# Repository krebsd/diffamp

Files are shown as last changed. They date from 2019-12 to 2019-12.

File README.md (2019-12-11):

# Differential Amplifier - diffamp

Differential Amplifier circuit for use for example in current sensing applications. The circuit is designed to be used in conjunction with an oscilloscope.

## PREFACE
This project and especially its documentation including this README is still in a very early state of development. This document will be updated with further information in the future.

## EDA

* [KiCad](http://kicad-pcb.org) - KiCad EDA is used for the PCB design

## Authors

* **David Krebs** - *Initial work* - [krebsd](https://github.com/krebsd)

## License

<br />This work is licensed under a <a rel="license" href="http://creativecommons.org/licenses/by-sa/4.0/">Creative Commons Attribution-ShareAlike 4.0 International License</a>

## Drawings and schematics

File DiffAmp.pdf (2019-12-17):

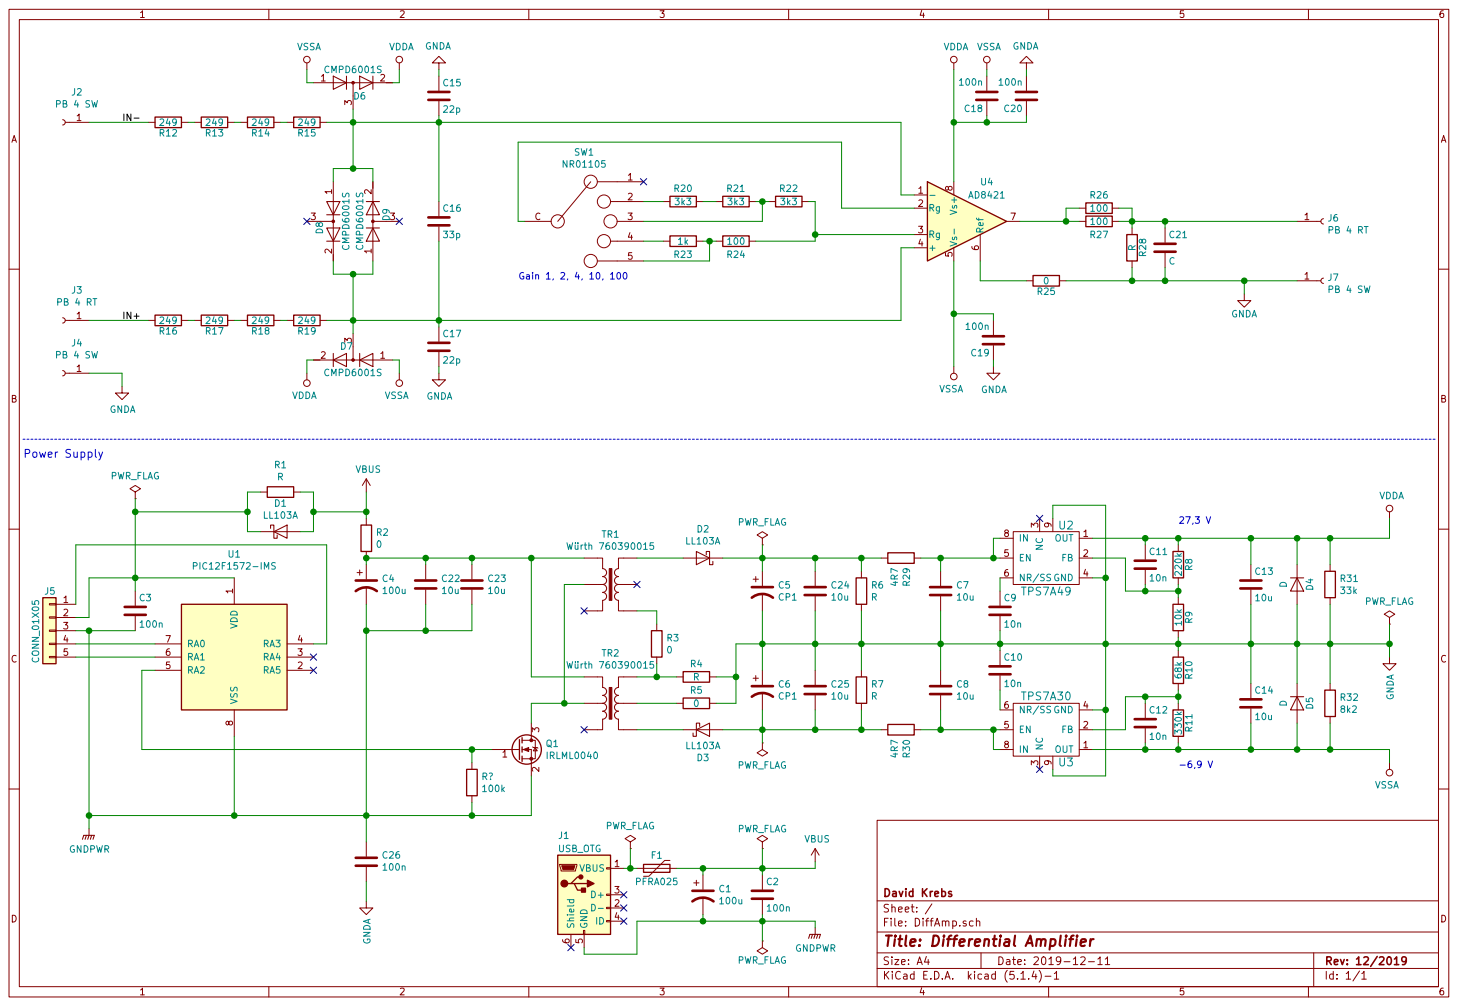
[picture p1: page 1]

File: DiffAmp.sch Sheet: / David Krebs D1

3 GND 4 EN 5 NR/SS 6

Id: 1/1 Title: Differential Amplifier

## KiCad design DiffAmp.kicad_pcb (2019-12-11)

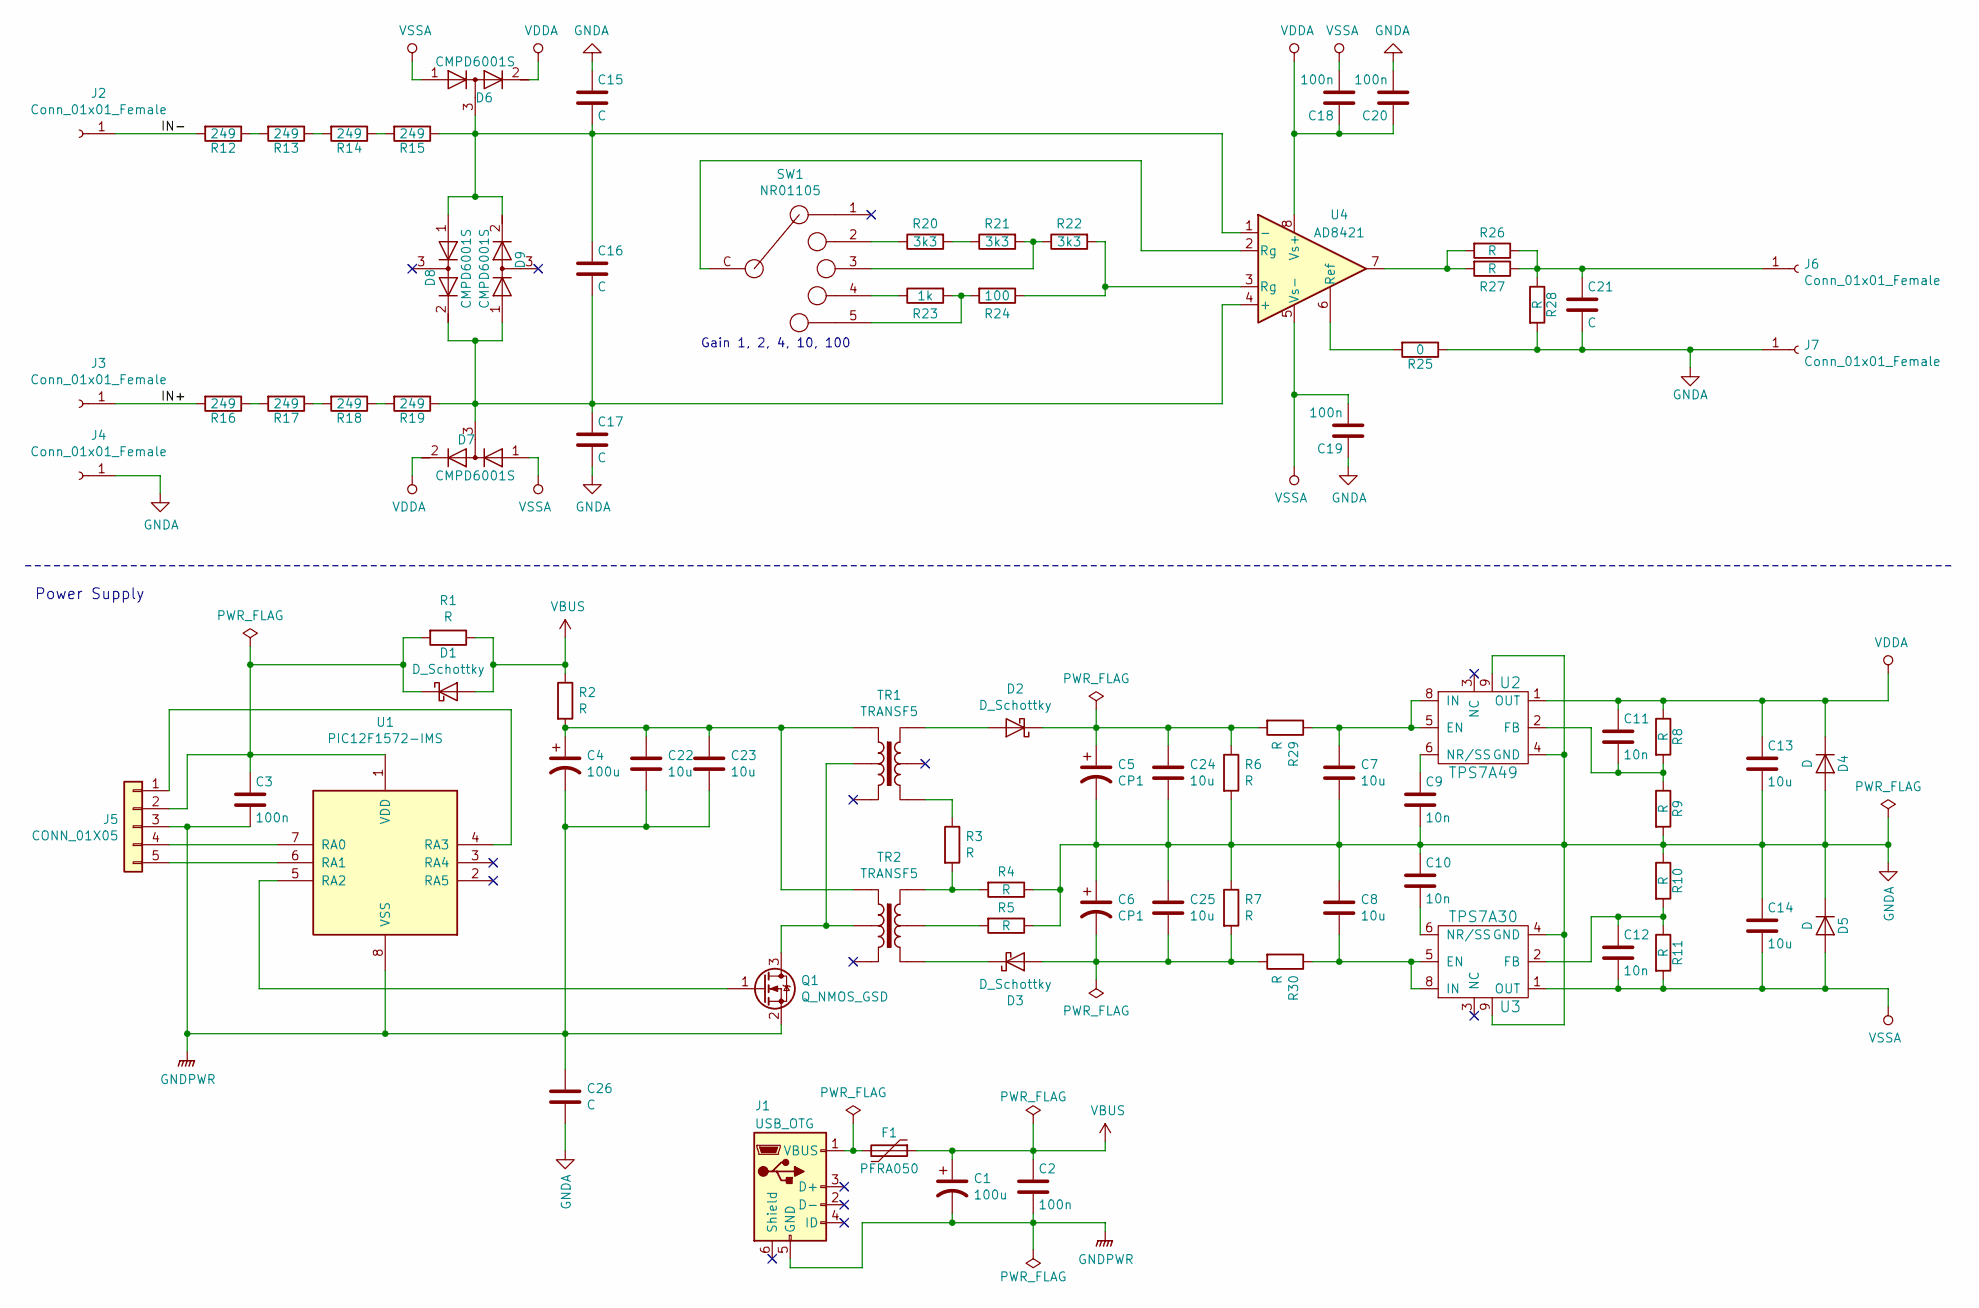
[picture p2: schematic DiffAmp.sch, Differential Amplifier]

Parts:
C1, C4: 100u; CP_Radial_D8.0mm_P3.50mm
C2, C3, C18, C19, C20: 100n; C_0805
C5, C6: CP1; CP_Radial_D8.0mm_P3.50mm
C7, C8, C22, C23, C24, C25: 10u; C_1210_3225Metric
C9, C10, C11, C12: 10n; C_0805
C13, C14: 10u; C_1210
C15, C16, C17, C21: C; C_0805
C26: C; C_0805_2012Metric
D1, D2, D3: D_Schottky; D_MiniMELF
D4, D5: D; D_MiniMELF
D6, D7, D8, D9: CMPD6001S; SOT-23
F1: PFRA050; R_Axial_DIN0204_L3.6mm_D1.6mm_P5.08mm_Horizontal
J1: USB_OTG; MIC_USB_BBU
J2, J3, J4, J6, J7: Conn_01x01_Female; PB4
J5: CONN_01X05; Pin_Header_Straight_1x05_Pitch2.54mm
Q1: Q_NMOS_GSD; SOT-23
R1, R2, R3, R4, R5, R29, R30: R; R_0805_SolderJumper
R6, R7, R8, R9, R10, R11, R26, R27, R28: R; R_0805
R12, R13, R14, R15, R16, R17, R18, R19: 249; R_0805
R20, R21, R22: 3k3; R_0805
R23: 1k; R_0805
R24: 100; R_0805
R25: 0; R_0805_SolderJumper
SW1: NR01105; NKK_NR01
TR1, TR2: TRANSF5; Würth_7603900XX
U1: PIC12F1572-IMS; MSOP-8_3x3mm_Pitch0.65mm
U2: TPS7A49; MSOP-8-1EP_3x3mm_Pitch0.65mm
U3: TPS7A30; MSOP-8-1EP_3x3mm_Pitch0.65mm
U4: AD8421; SOIC-8_3.9x4.9mm_Pitch1.27mm

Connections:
/IN+: J3.1, R16.2
/IN-: J2.1, R12.2
GNDA: C5.2, C6.1, C7.2, C8.1, C9.2, C10.1, C13.2, C14.1, C15.1, C17.2, C19.1, C20.2, C21.2, C24.2, C25.1, C26.1, D4.2 (A), D5.1 (K), J4.1, J7.1, R4.1, R5.1, R6.2, R7.1, R9.2, R10.1, R25.1, R28.2, U2.4 (GND), U2.9, U3.4 (GND), U3.9
GNDPWR: C1.2, C2.2, C3.2, C4.2, C22.2, C23.2, C26.2, J1.5 (GND), J5.3, Q1.2 (S), U1.8 (VSS)
unnamed: C3.1, D1.1 (K), J5.2, R1.2, U1.1 (VDD)
unnamed: C7.1, R29.1, U2.5 (EN), U2.8 (IN)
unnamed: C8.2, R30.1, U3.5 (EN), U3.8 (IN)
unnamed: C9.1, U2.6 (NR/SS)
unnamed: C10.2, U3.6 (NR/SS)
unnamed: C11.2, R8.2, R9.1, U2.2 (FB)
unnamed: C12.1, R10.2, R11.1, U3.2 (FB)
unnamed: C15.2, C16.1, D6.3 (common), D8.1 (A), D9.2 (K), R15.1, U4.1 (-)
unnamed: C16.2, C17.1, D7.3 (common), D8.2 (K), D9.1 (A), R19.1, U4.4 (+)
unnamed: C21.1, J6.1, R26.1, R27.1, R28.1
unnamed: C4.1, C22.1, C23.1, R2.2, TR1.1, TR2.1
unnamed: C5.1, C24.1, D2.1 (K), R6.1, R29.2
unnamed: C6.2, C25.2, D3.2 (A), R7.2, R30.2
unnamed: D2.2 (A), TR1.6
unnamed: D3.1 (K), TR2.4
unnamed: F1.2, J1.1 (VBUS)
unnamed: J5.1, U1.4 (RA3)
unnamed: J5.4, U1.7 (RA0)
unnamed: J5.5, U1.6 (RA1)
unnamed: Q1.1 (G), U1.5 (RA2)
unnamed: Q1.3 (D), TR1.2, TR2.2
unnamed: R3.1, TR1.4
unnamed: R3.2, R4.2, TR2.6
unnamed: R5.2, TR2.5
unnamed: R12.1, R13.2
unnamed: R13.1, R14.2
unnamed: R14.1, R15.2
unnamed: R16.1, R17.2
unnamed: R17.1, R18.2
unnamed: R18.1, R19.2
unnamed: R20.1, SW1.2
unnamed: R20.2, R21.1
unnamed: R21.2, R22.1, SW1.3
unnamed: R22.2, R24.1, U4.3 (Rg)
unnamed: R23.1, SW1.4
unnamed: R23.2, R24.2, SW1.5
unnamed: R25.2, U4.6 (Ref)
unnamed: R26.2, R27.2, U4.7
unnamed: SW1.C, U4.2 (Rg)
VBUS: C1.1, C2.1, D1.2 (A), F1.1, R1.1, R2.1
VDDA: C11.1, C13.1, C18.1, C20.1, D4.1 (K), D6.2 (K), D7.2 (K), R8.1, U2.1 (OUT), U4.8 (Vs+)
VSSA: C12.2, C14.2, C18.2, C19.2, D5.2 (A), D6.1 (A), D7.1 (A), R11.2, U3.1 (OUT), U4.5 (Vs-)

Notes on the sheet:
Power Supply
Gain 1, 2, 4, 10, 100

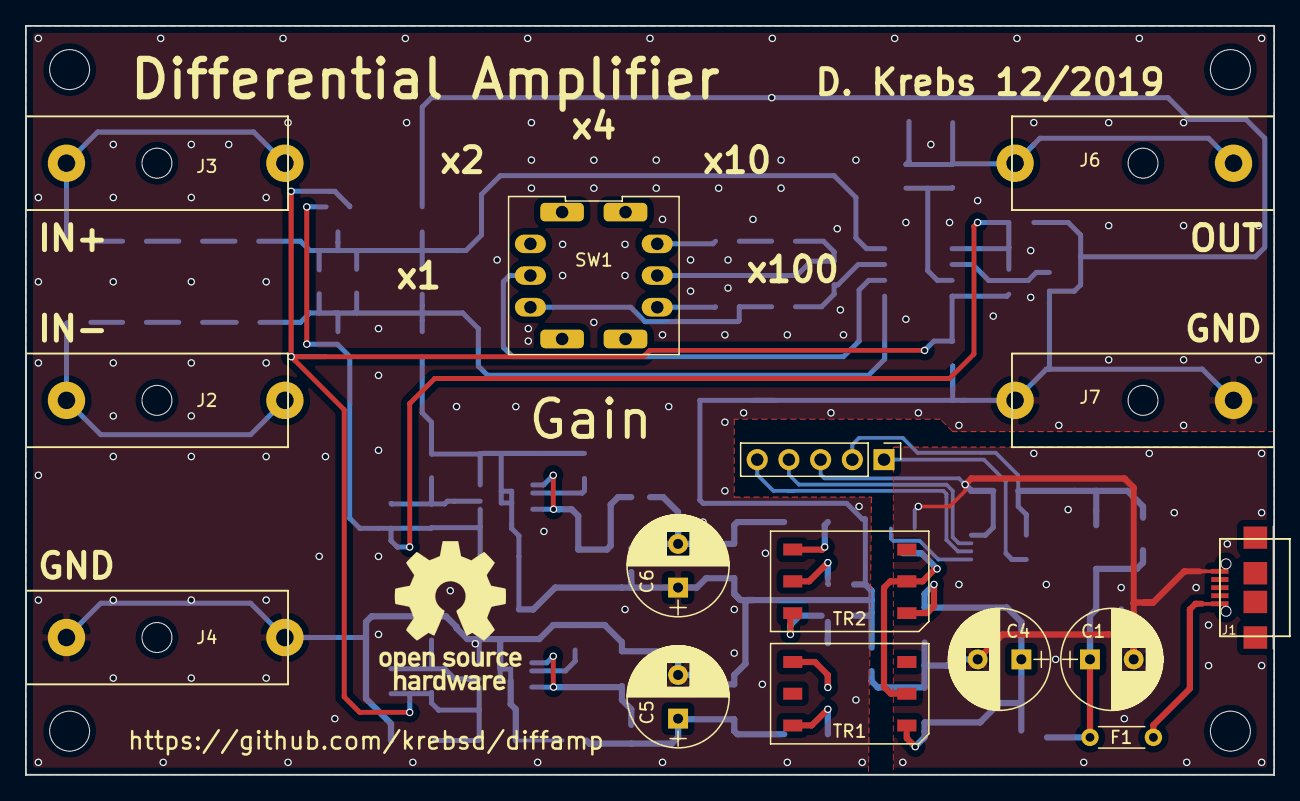
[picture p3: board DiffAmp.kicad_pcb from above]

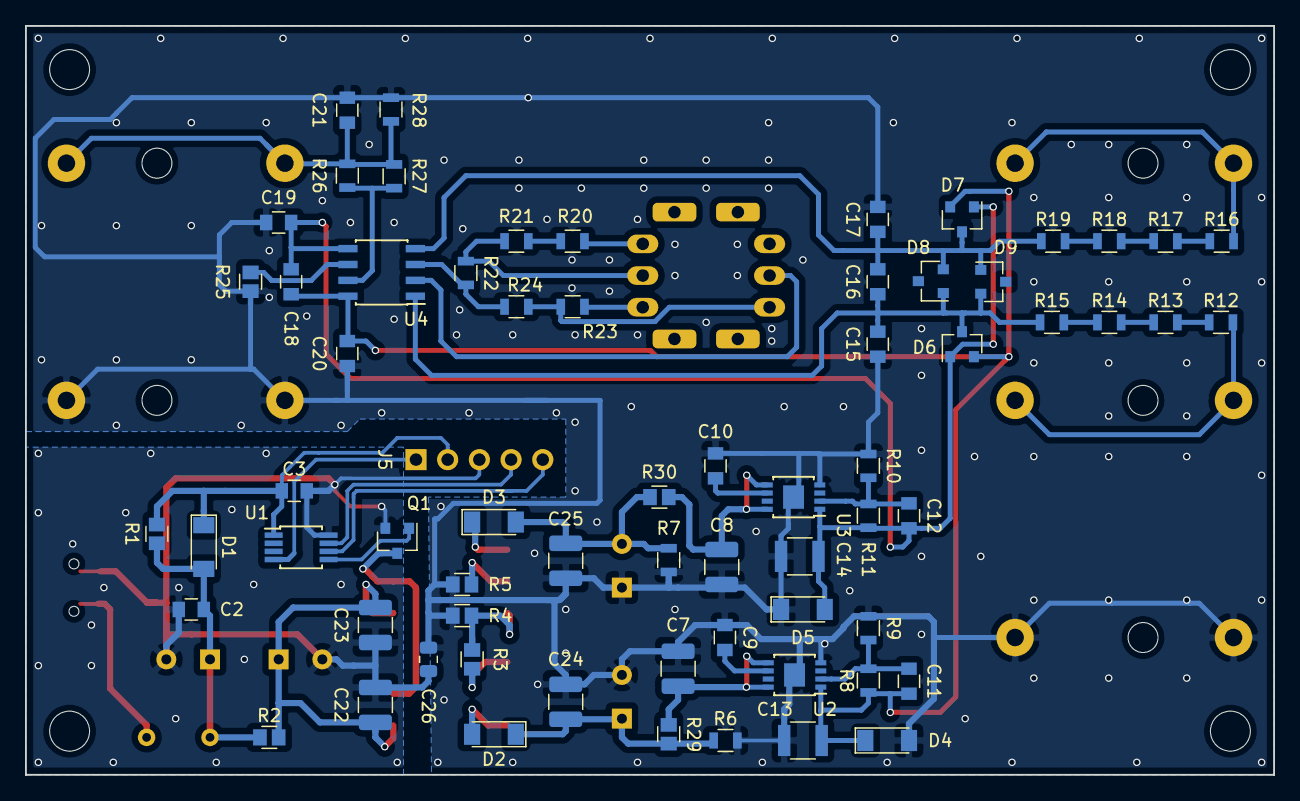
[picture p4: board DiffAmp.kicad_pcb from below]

Board: 2 copper layers, 100.0 x 60.0 mm, 81 parts (66 on the bottom side), 46 nets.

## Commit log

2019-12-11 Commit of KiCad Project including used footprints
    [DiffAmp.kicad_pcb, DiffAmp.sch]
2019-12-11 Added preliminary pdf-schematic
2019-12-16 Changes in first assembly added to schematic
    [DiffAmp.sch]
2019-12-17 Schematic revised - change in negative supply voltage
    [DiffAmp.sch]
